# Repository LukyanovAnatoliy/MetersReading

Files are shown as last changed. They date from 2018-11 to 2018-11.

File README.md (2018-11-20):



[Habrahabr](https://habr.com/post/428844/)

## MetersReading
Данное устройство предназначено для сбора данных по расходу воды, электроэнергии, можно следить за датчиками протечки или использовать для чего-то другого, где необходимо отслеживать состояние выводов. Для хранения данных используется сервис [thingspeak](https://thingspeak.com/). В качестве основного модуля использовалась ESP-03. Прошивка модуля собрана при помощи [online-конструктора](http://nodemcu-build.com)

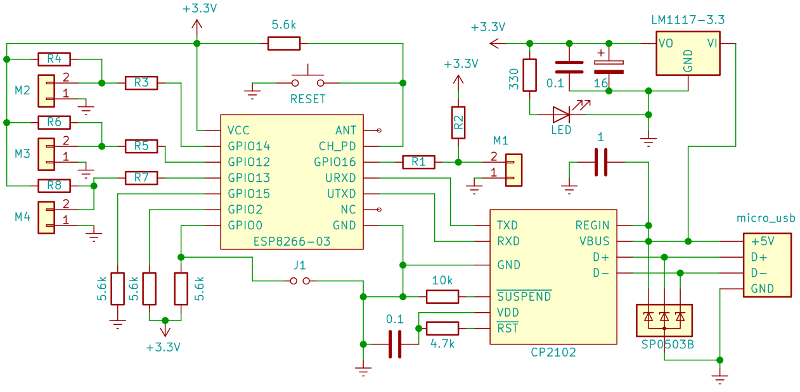
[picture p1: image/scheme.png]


## Настройка
При старте устройство переходит в режим настройки. После этого, в списке доступных сетей должна появиться сеть ESP-???????, где вместо символов ? будет id вашего ESP. Пароль для подключения к сети "1234567890". После подключения, в браузере необходимо перейти по адресу 1.1.1.1. В данной версии скрипта доступно два режима: учет потребления воды и учет потребления электроэнергии

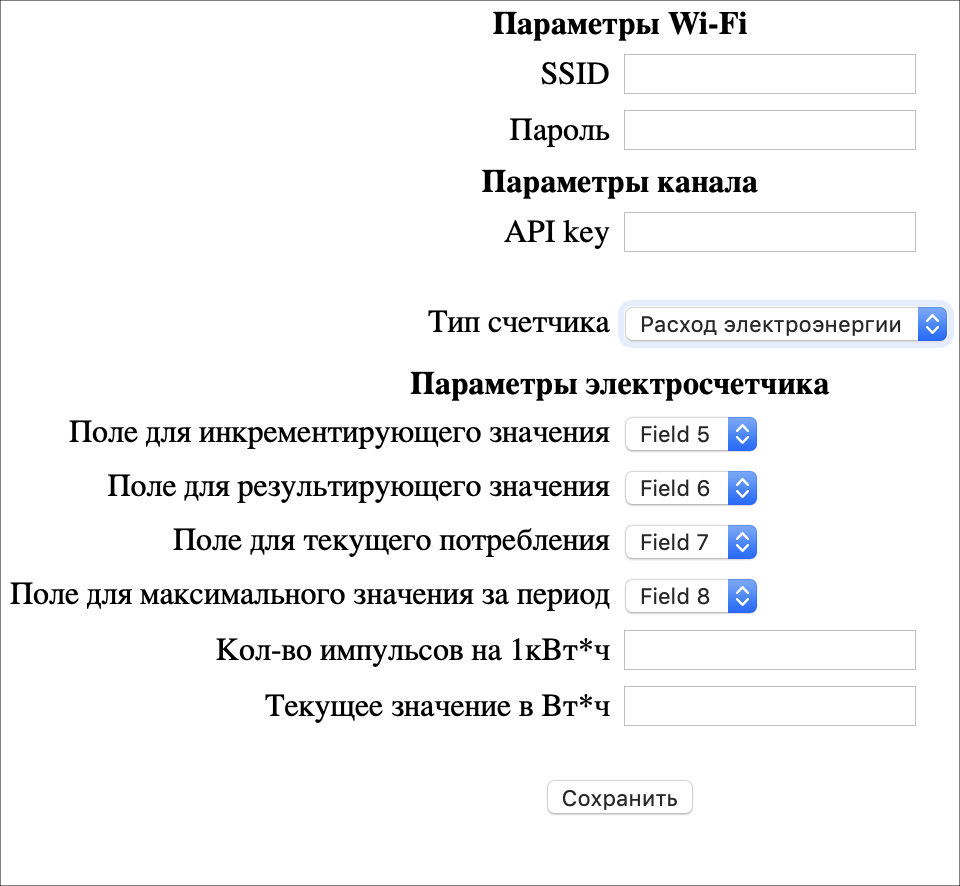
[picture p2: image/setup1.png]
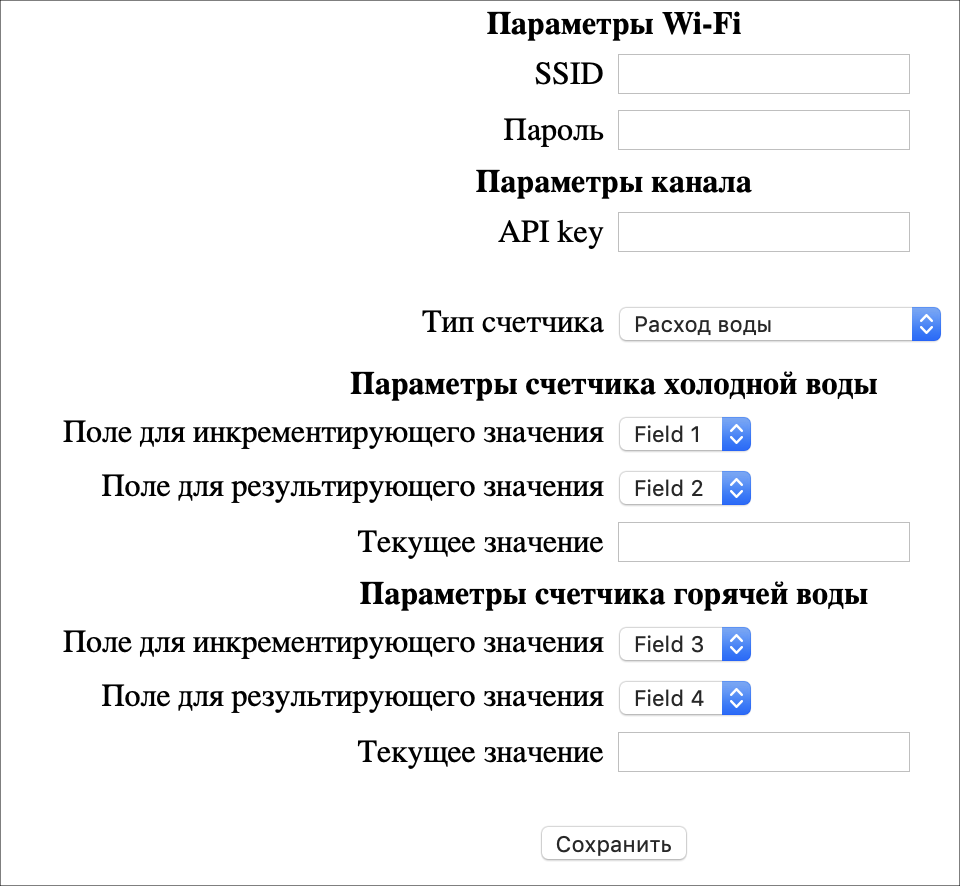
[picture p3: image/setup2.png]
 

После ввода всех настроек, необходимо нажать на кнопку "Сохранить". Если к устройству не подключаться, то через 60 секунд устройство перейдет в рабочий режим.

## Принцип работы
При работе с водосчетчиками устройство передает данные каждые 60 секукнд, при условии что были изменения. При работе с электросчетчиком данные передаются каждые 20 секунд.
Если необзходимо, скрипт можно доработать как нужно. Например одновременно подключить к устройству счетчики воды, датчик протечки и светодиод для индикации работы или 2 счетчика воды и 2 датчика протечки. Вариантов много.

## Приложение
Приложение работает с сервисом [thingspeak](https://thingspeak.com/) и ему не важно кто туда передает данные. 

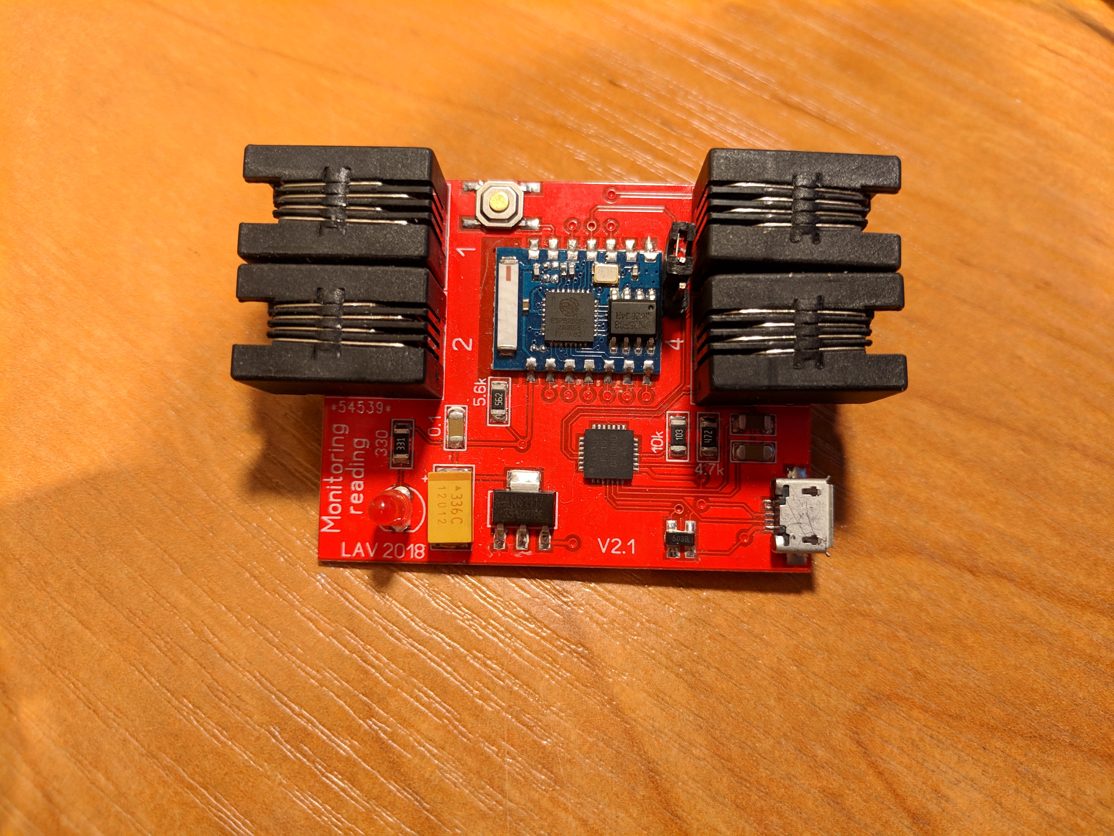
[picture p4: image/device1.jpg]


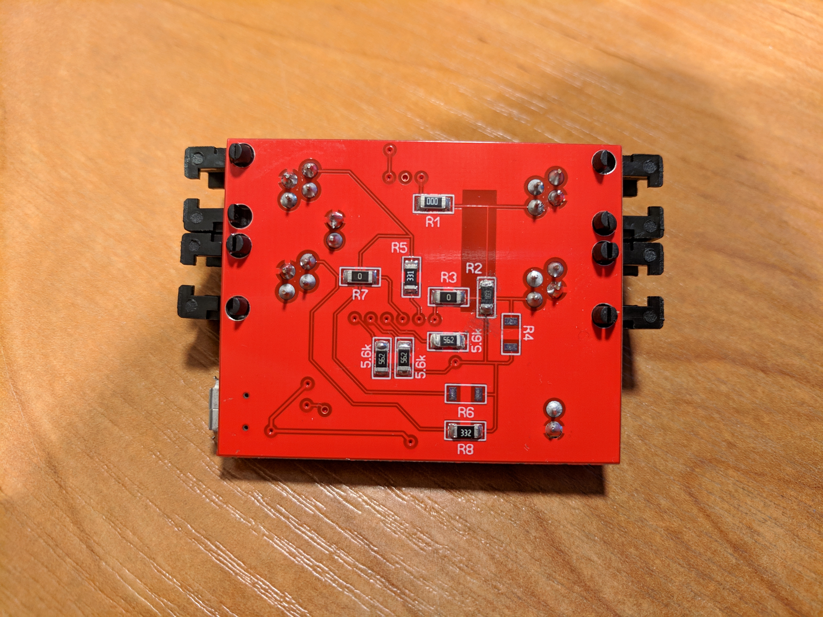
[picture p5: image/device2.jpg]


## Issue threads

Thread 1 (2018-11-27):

20 или 60сек?

loukash, 2018-11-27:
https://github.com/LukyanovAnatoliy/MetersReading/blob/fcfb55efffda66ed406f30fc0a704bb074b1d543/setup_mode.lua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

Разве это не 20 сек?

LukyanovAnatoliy, 2018-11-27:
Точно. Спасибо. Осталось после отладки

Closed 2018-11-27.

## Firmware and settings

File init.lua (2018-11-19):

INPUT1=0; -- GPIO16
INPUT2=5; -- GPIO14
INPUT3=6; -- GPIO12 
INPUT4=7; -- GPIO13

LED_GPIO = INPUT3; 
COLD_GPIO = INPUT1; 
HOT_GPIO = INPUT2;
POWER_GPIO = INPUT4;

node.setcpufreq(node.CPU80MHZ);

INC_VALUE = 10; -- инкрементирующее значение в литрах

TYPE_WATER_METER = "1";
TYPE_POWER_METER = "2";

PARAM_SSID = "ssid";
PARAM_PASSWORD = "password";
PARAM_API_KEY = "api_key";
PARAM_COLD_FIELD_INC = "cold_field_incr";
PARAM_COLD_FIELD_TOTAL = "cold_field_total";
PARAM_COLD_VALUE = "cold_value";
PARAM_HOT_FIELD_INC = "hot_field_incr";
PARAM_HOT_FIELD_TOTAL = "hot_field_total";
PARAM_HOT_VALUE = "hot_value";
PARAM_POWER_FIELD_INC = "power_field_incr";
PARAM_POWER_FIELD_TOTAL = "power_field_total";
PARAM_POWER_VALUE = "power_value";
PARAM_POWER_FIELD_CURRENT_CONS = "power_field_current_cons";
PARAM_POWER_FIELD_MAX_VALUE = "power_field_max_value";
PARAM_TYPE_ACCOUNTING = "type_meter";
PARAM_COUNT_IMPULS_IN_KW = "count_impuls_in_kW";

FILE_MAIN_PARAMETERS = "main_parameters";
FILE_COLD = "cold";
FILE_HOT = "hot";
FILE_POWER = "power";

settings = {};
cold_values = {};
hot_values = {};
power_values = {};

-- настройка GPIO
--gpio.mode(LED_GPIO, gpio.OUTPUT)
--gpio.mode(BUTTON_GPIO, gpio.INPUT, gpio.PULLUP);

-- настройка GPIO
gpio.mode(LED_GPIO, gpio.OUTPUT);
gpio.mode(COLD_GPIO, gpio.INPUT, gpio.PULLUP);
gpio.mode(HOT_GPIO, gpio.INPUT, gpio.PULLUP);
gpio.mode(POWER_GPIO, gpio.INPUT, gpio.PULLUP);

-- включение светодиода
function led_on()
    gpio.write(LED_GPIO, gpio.HIGH);
end;

-- отключение светодиода  
function led_off()
    gpio.write(LED_GPIO, gpio.LOW);
end;

function invert_led()
    if (gpio.read(LED_GPIO) == 1) then
        led_off();
    else
        led_on();
    end;
end;

function val_to_str ( v )
    return ((v == nil) or (v == "")) and '""' or '"'..v..'"'
end;

-- перевод таблицы в строку 
function table_to_str(tbl)
    local result = {}
    for k, v in pairs(tbl) do
        table.insert( result, k .. "=" .. val_to_str( v ) )
    end
    return "{" .. table.concat( result, "," ) .. "}"
end;

-- сохранение таблицы в файл 
function write_to_file(fileName, tbl)
    file.open(fileName, "w+");
    file.write(table_to_str(tbl));
    file.flush();
    file.close();
end;

-- чтение данных из файла
function read_from_file(fileName)
    if (file.open(fileName, "r")) then
        str = file.read();
        file.close();
        if (str == nil) or (str == "") then
            return {};
        else
            return loadstring("return "..str)();
        end;
    else 
        return {}
    end;
end;

-- 
function showError()
    tmr.alarm(0, 500, tmr.ALARM_AUTO, function() 
            invert_led();
        end) 
end;

function setup_wifi_as_station()
    wifi.sta.clearconfig();
    -- подключаемся к wifi точке 
    wifi.setmode(wifi.STATION);
    station_cfg={}
    station_cfg.ssid=settings[PARAM_SSID]
    station_cfg.pwd=settings[PARAM_PASSWORD]
    wifi.sta.config(station_cfg);
    wifi.sta.autoconnect(1);
    wifi.sta.connect();
end;

settings = read_from_file(FILE_MAIN_PARAMETERS);
cold_values = read_from_file(FILE_COLD);
hot_values = read_from_file(FILE_HOT);
power_values = read_from_file(FILE_POWER);


-- зададим начальные значения если ничего не задано
if (cold_values.total == nil) then
    cold_values.inc = 0;
    cold_values.total = 0;
end;

if (hot_values.total == nil) then
    hot_values.inc = 0;
    hot_values.total = 0;
end;

if (power_values.total == nil) then
    power_values.inc = 0;
    power_values.total = 0;
end;

if (settings[PARAM_SSID] == nil) then
    settings[PARAM_SSID] = "";
    settings[PARAM_PASSWORD] = "";
    settings[PARAM_API_KEY] = "";
    settings[PARAM_COLD_FIELD_INC] = "";
    settings[PARAM_COLD_FIELD_TOTAL] = "";
    settings[PARAM_HOT_FIELD_INC] = "";
    settings[PARAM_HOT_FIELD_TOTAL] = "";
    settings[PARAM_POWER_FIELD_INC] = "";
    settings[PARAM_POWER_FIELD_TOTAL] = "";
    settings[PARAM_TYPE_ACCOUNTING] = TYPE_WATER_METER;
    settings[PARAM_COUNT_IMPULS_IN_KW] = "";
    settings[PARAM_POWER_FIELD_CURRENT_CONS] = "";
    settings[PARAM_POWER_FIELD_MAX_VALUE] = "";
end;

print(table_to_str(settings));

--adc.force_init_mode(adc.INIT_VDD33);

-- всегда при старте запускаем режим настройки
-- если в течение 60 секунд никто не подключился и были введены настройки точки доступа, 
-- то отключаем режим настройки и запускаем считывание показаний
dofile("setup_mode.lua");

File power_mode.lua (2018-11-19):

print("Start power accounting");

-- подключаемся к wifi точке 
setup_wifi_as_station()

local MAX_INT = 2147483647;
local MICRO_W = 100000;

-- настройка GPIO
gpio.mode(POWER_GPIO, gpio.INPUT, gpio.PULLUP)

-- если не задано кол-во импульсов на кВт*ч, то это ошибка
if (settings[PARAM_COUNT_IMPULS_IN_KW] == nill) or
    (settings[PARAM_COUNT_IMPULS_IN_KW] == "") then

    showError();
    return;

end;

local count_imp_in_kW = settings[PARAM_COUNT_IMPULS_IN_KW];
local min_count_imp_for_inc_total = count_imp_in_kW / 200; -- инкримируем итоговое значением минимум на 0.5%
local value_for_inc_total = 1000 / 200; -- инкримируем итоговое значением минимум на 0.5% => 5Вт*ч
local value_for_inc_current_cons = 1000 * MICRO_W / count_imp_in_kW; -- 1кВт*ч / count_imp_in_kW

local current_cons = 0;
local max_value = 0;
local last_imp_time = tmr.now();
local prev_trig_time = tmr.now();
local prev_diff_time = 0;

local count_tick = 0;

local prev_state = 0;
-- функция проверки состояния выводов и инкрементации показаний
local function check_power_input_state()

    trig_time = tmr.now();

    -- при переполнении счетчика прошедшего времени с момента запуска устройства
    -- отсчет начинается с нуля
    if (trig_time > prev_trig_time) then
        diff_time = trig_time - prev_trig_time;
    else
        diff_time = trig_time  + (MAX_INT - prev_trig_time);
    end;

    if (gpio.read(POWER_GPIO) == 1 and prev_state == 0) then

        prev_trig_time = trig_time;

        if (trig_time > last_imp_time) then
            duration = (trig_time - last_imp_time) / 1000;
        else
            duration = (trig_time + (MAX_INT - last_imp_time)) / 1000;
        end
        
        if (duration == 0) then
            return;
        end;
        last_imp_time = trig_time;

        current_cons = (1000 * (3600000 / count_imp_in_kW)) / duration;
        if current_cons > max_value then
            max_value = current_cons;
        end;

        count_tick = count_tick + 1;
        power_values.inc = power_values.inc + value_for_inc_current_cons;
        if (count_tick == min_count_imp_for_inc_total) then
            power_values.total = power_values.total + value_for_inc_total; 
            count_tick = 0;
            write_to_file(FILE_POWER, power_values);
        end;

        prev_state = 0;
        invert_led();
        
    end;
    prev_state = gpio.read(POWER_GPIO);
end;

-- каждые 10 мс проверяем состояние выводов
tmr.alarm(2, 10, tmr.ALARM_AUTO, check_power_input_state)

-- функция отправки данных на сервер
local function send_power_to_server()
    print("Try send power");
    print("power_values", table_to_str(power_values), "max_value", max_value);

    -- если нет подключения, выходим
    if (wifi.sta.status() ~= wifi.STA_GOTIP) then
        return;
    end;

    local inc_value = power_values.inc / MICRO_W;
    power_values.inc = power_values.inc - inc_value * MICRO_W;
    write_to_file(FILE_POWER, power_values);

    local s_max_value = max_value;
    max_value = 0;
    local s_current_cons = current_cons;
    current_cons = 0;
    
    -- отправка данных
    conn = net.createConnection(net.TCP, 0)
    conn:on("receive", function(con, receive)

        --print(receive);
        con:close();
    
    end)
    conn:on("connection", function(c)
        local param_str = "";
        param_str = "&"..settings[PARAM_POWER_FIELD_INC].."="..tostring(inc_value).."&"..
                         settings[PARAM_POWER_FIELD_TOTAL].."="..tostring(power_values.total).."&"..
                         settings[PARAM_POWER_FIELD_CURRENT_CONS].."="..tostring(s_current_cons).."&"..
                         settings[PARAM_POWER_FIELD_MAX_VALUE].."="..tostring(s_max_value);
        
        c:send("GET /update?key="..settings[PARAM_API_KEY]..param_str
            .." HTTP/1.1\r\n"
            .."Host: api.thingspeak.com\r\n"
            .."Connection: keep-alive\r\n"
            .."Accept: */*\r\n"
            .."\r\n");
    end)
    conn:on("disconnection", function(c, error)
        print("error = "..error);
        power_values.inc = power_values.inc + inc_value * MICRO_W;
        write_to_file(FILE_POWER, power_values);
    end)
    conn:connect(80,"api.thingspeak.com");
end;

--каждые 20 секунд отправляем данные на сервер
tmr.alarm(1, 20000, tmr.ALARM_AUTO, send_power_to_server);

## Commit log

2018-11-20 обновил картинки
2018-11-20 добавил фото девайса и gerber-файлы
    [meters_reading.drl, meters_reading.gbl, meters_reading.gbo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]
2018-11-27 Update setup_mode.lua
    поправил время отключения режима настройки
